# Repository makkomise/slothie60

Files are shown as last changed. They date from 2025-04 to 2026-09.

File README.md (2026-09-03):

# Slothie60

## 60% ISO keyboard

- GH60-Compatible
- Underglow
- Support for split Right Shift and stepped Caps
- Support for QMK/VIAL






ORDERING AT YOUR OWN RESPONSIBILITY! While i have confirmed that this works, order at your own discretion.

Version 2a is a work in progress, 1b is the finished one so if you want to get one, pick that.
KiCad folder includes all the project files, feel free to modify to your own liking. 
Production folder includes all the needed files for ordering these. Zip has all the gerbers, BOM and POS files are needed if you order it assembled.
Firmware-folder has all the files needed for you to either modify and compile yourself, or you can just download the binary and flash it in QMK Toolbox.

Keyboard made under CERN-OHL-W v2 license.

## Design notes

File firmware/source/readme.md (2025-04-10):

# slothie60

slothie60

*60% ISO keyboard, support for GH60-cases, RGB underglow.*

* Keyboard Maintainer: [makkomise](https://github.com/makkomise)
* Hardware Availability: [github/makkomise/slothie60](https://github.com/makkomise/slothie60)

Make example for this keyboard (after setting up your build environment):

    make slothie60:default

Flashing example for this keyboard:

    make slothie60:default:flash

See the [build environment setup](https://docs.qmk.fm/#/getting_started_build_tools) and the [make instructions](https://docs.qmk.fm/#/getting_started_make_guide) for more information. Brand new to QMK? Start with our [Complete Newbs Guide](https://docs.qmk.fm/#/newbs).

## Bootloader

Enter the bootloader in 3 ways:

* **Bootmagic reset**: Hold down the key at (0,0) in the matrix (usually the top left key or Escape) and plug in the keyboard
* **Physical reset button**: Briefly press the button on the back of the PCB
* **Keycode in layout**: Press FN + Esc

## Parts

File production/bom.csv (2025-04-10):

Designator | Footprint | Quantity | Value | LCSC Part #
BOOTSW1 | SW_SPST_TL3342 | 1 | SW_Push | C115351
BOOT_R1 | 0603 | 1 | 10k | C25804
D1, D10, D11, D12, D13, D14, D15, D16, D17, D18, D19, D2, D20, D21, D22, D23, D24, D25, D26, D27, D28, D29, D3, D30, D32, D33, D4, D5, D6, D7, D8, D9 | SOT-23 | 32 | BAV70 | C2501
ESD1 | SOT-23-6 | 1 | USBLC6-2SC6 | C2827654
F1 | 1206 | 1 | 500mA | C135338
LED1, LED10, LED11, LED12, LED13, LED14, LED15, LED16, LED2, LED3, LED4, LED5, LED6, LED7, LED8, LED9 | LED_WS2812B_PLCC4_5.0x5.0mm_P3.2mm | 16 | Worldsemi_WS2812C | C114587
MCU1 | LQFP-48_7x7mm_P0.5mm | 1 | STM32F072CBT6 | C915660
MCU_C1, MCU_C2, MCU_C3, MCU_C5, MCU_C8 | 0603 | 5 | 100nF | C1591
MCU_C4, MCU_C9 | 0603 | 2 | 4.7uF | C19666
MCU_C6 | 0603 | 1 | 10nF | C57112
MCU_C7, REG_C1, REG_C2 | 0603 | 3 | 1uF | C15849
REG1 | SOT-23-3 | 1 | XC6206 | C5446
USB1 | USB_C_Receptacle_HRO_TYPE-C-31-M-12 | 1 | USB_C | C165948
USB_R1, USB_R2 | 0603 | 2 | 5.1k | C23186

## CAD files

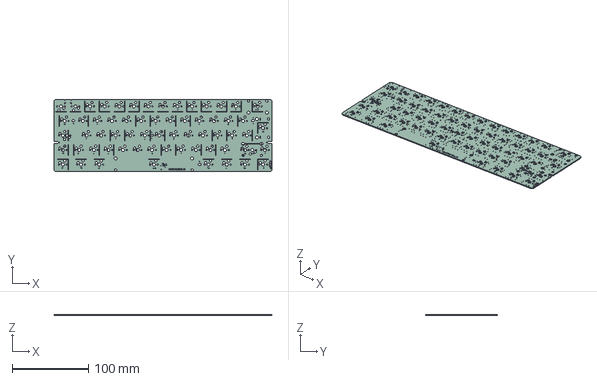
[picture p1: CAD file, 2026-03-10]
KiCad Files/rev1b/Slothie60_rev1b-rounded.step
285.0 x 94.6 x 1.26 mm
Slothie60_rev1b-rounded_silkscreen x 2
Slothie60_rev1b-rounded_PCB

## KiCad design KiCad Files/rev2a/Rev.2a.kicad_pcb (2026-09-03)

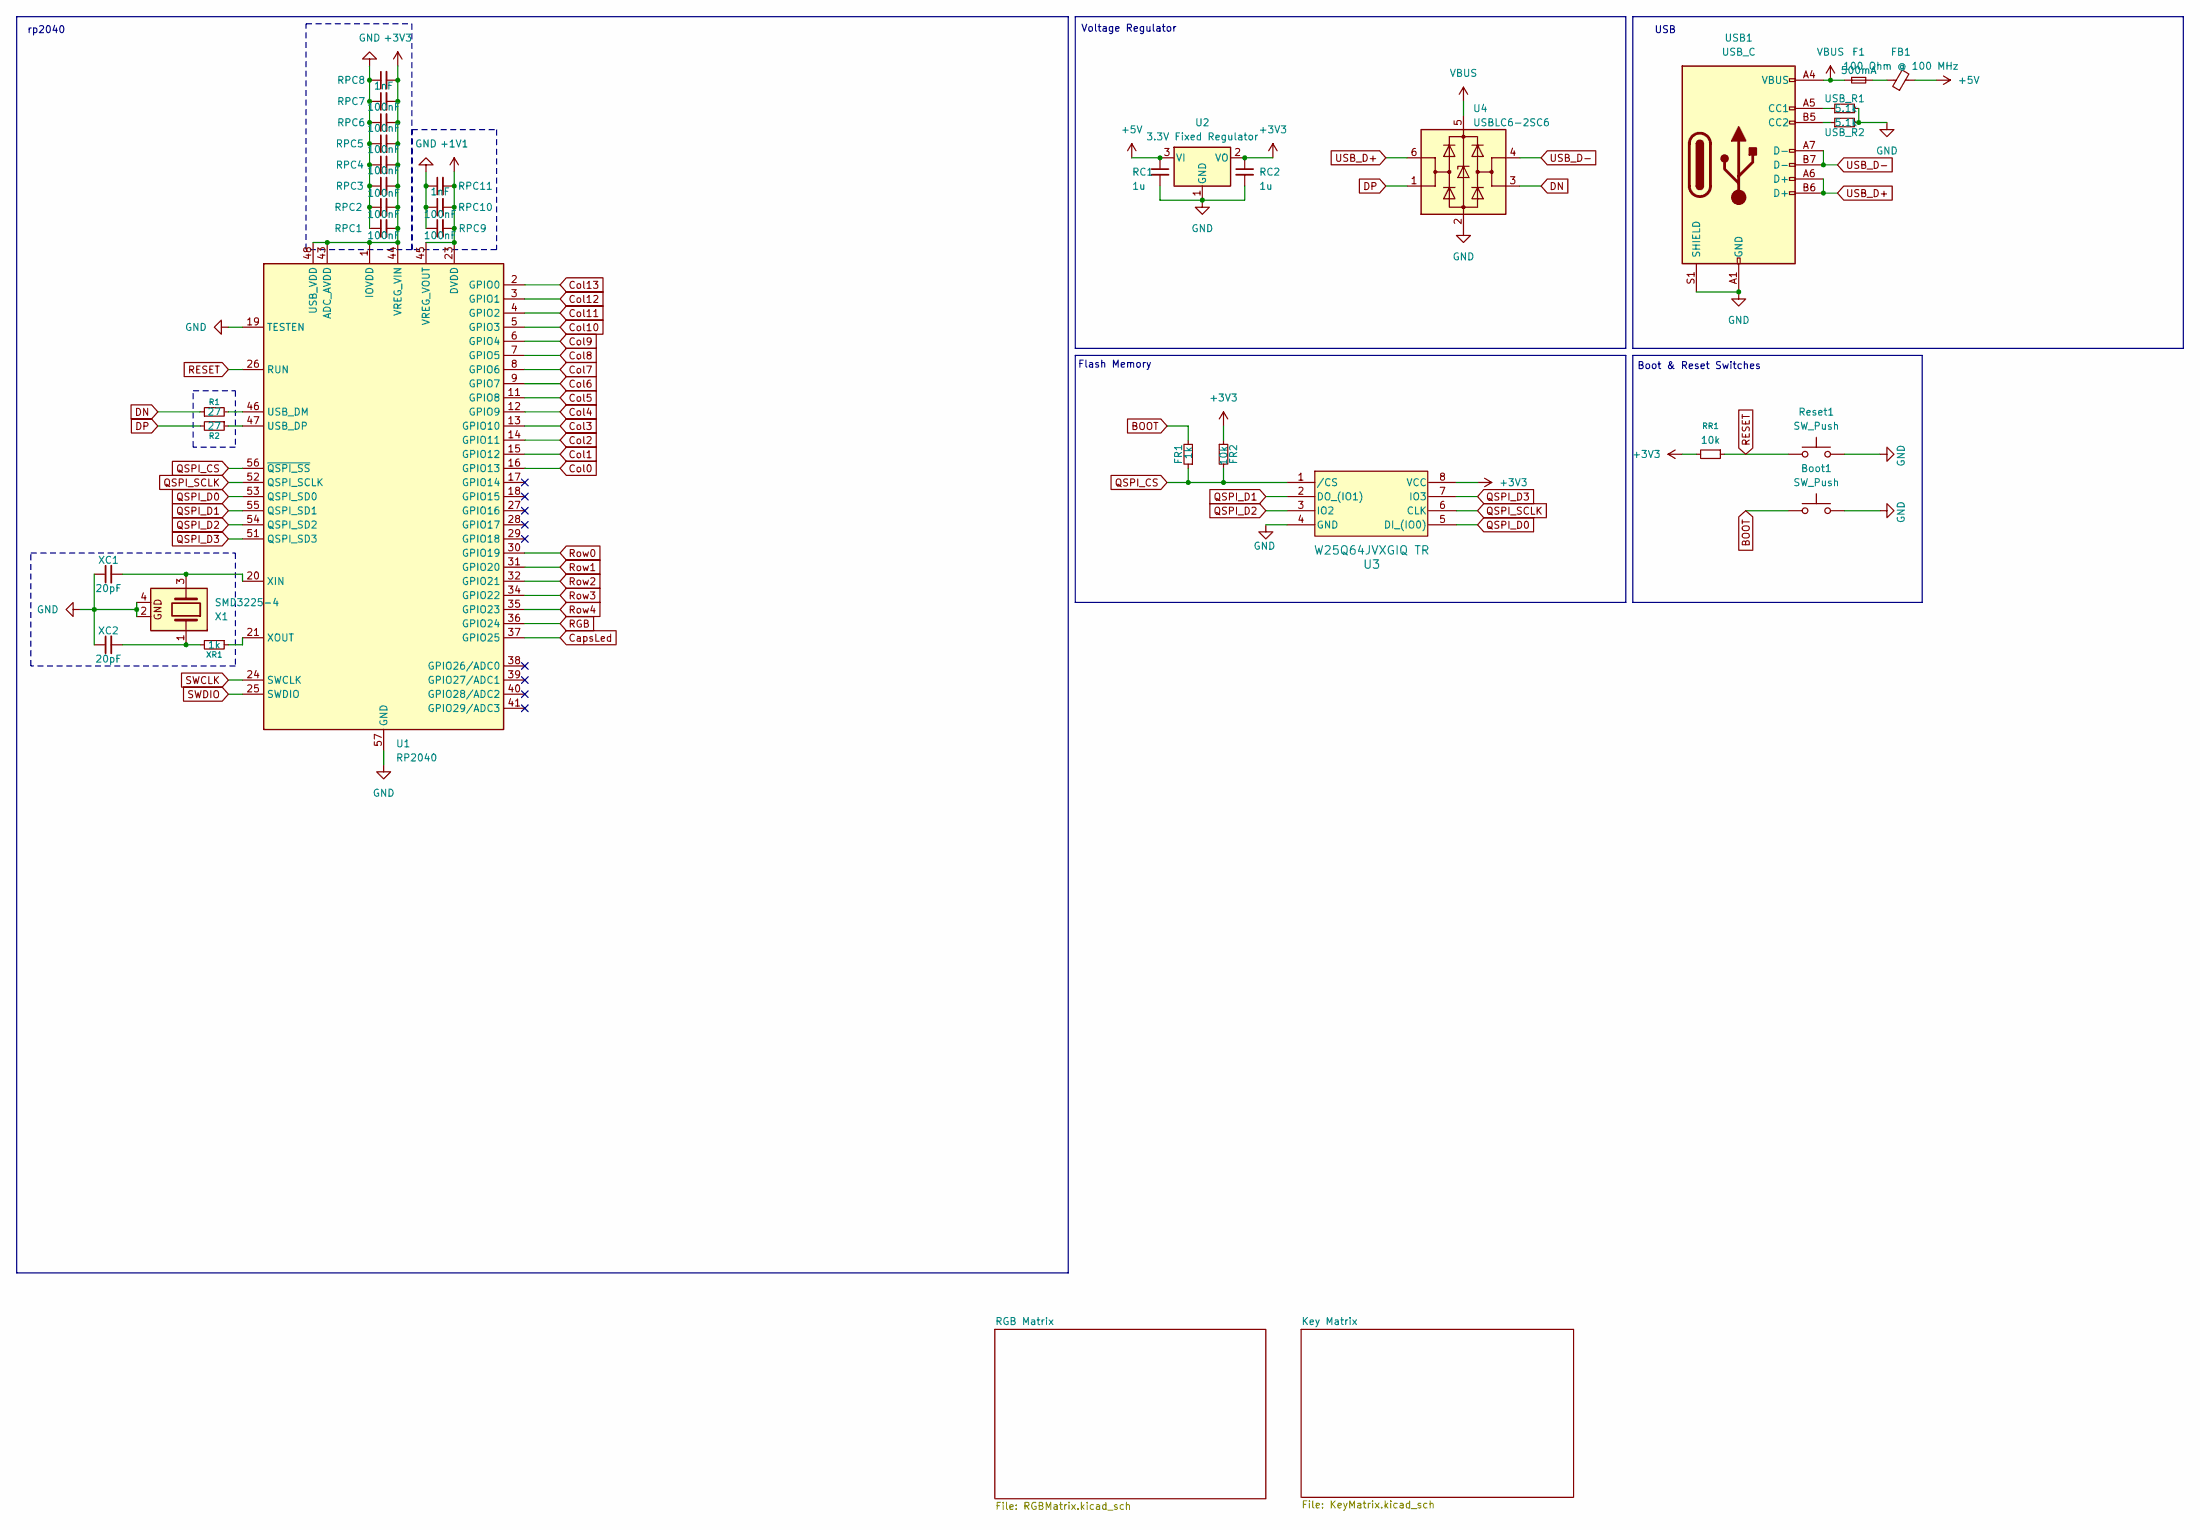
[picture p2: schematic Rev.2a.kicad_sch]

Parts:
Boot1: SW_Push; SW_SPST_B3U-1000P; LCSC C231329
F1: 500mA; Fuse_1206_3216Metric_Castellated; LCSC C135338
FB1: 100 Ohm @ 100 MHz; L_0402_1005Metric; LCSC C85812
FR1: 1k; R_0402_1005Metric; LCSC C23186
FR2: 10k; R_0402_1005Metric; LCSC C23186
R1, R2: 27; R_0402_1005Metric; LCSC C25100
RC1, RC2: 1u; C_0402_1005Metric; LCSC C52923
RPC1, RPC2, RPC3, RPC4, RPC5, RPC6, RPC7, RPC9, RPC10: 100nF; C_0402_1005Metric; LCSC C307331
RPC8, RPC11: 1nF; C_0402_1005Metric; LCSC C14442
RR1: 10k; R_0402_1005Metric; LCSC C23186
Reset1: SW_Push; SW_SPST_B3U-1000P; LCSC C231329
U1: RP2040; QFN-56-1EP_7x7mm_P0.4mm_EP3.2x3.2mm; LCSC C2040
U2: 3.3V Fixed Regulator; TSOT-23; LCSC C150715
U3: W25Q64JVXGIQ TR; XSON-8-EP(4x4); LCSC C2940195
U4: USBLC6-2SC6; SOT-23-6; LCSC C558442
USB1: USB_C; USB_C_Receptacle_HRO_TYPE-C-31-M-12; LCSC C165948
USB_R1, USB_R2: 5.1k; R_0402_1005Metric; LCSC C23186
X1: SMD3225-4; Crystal_SMD_3225-4Pin_3.2x2.5mm; LCSC C9002
XC1, XC2: 20pF; C_0402_1005Metric; LCSC C1554
XR1: 1k; R_0402_1005Metric; LCSC C23186

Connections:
+1V1: RPC9.2, RPC10.2, RPC11.2, U1.23 (DVDD), U1.45 (VREG_VOUT), U1.50 (DVDD)
+3V3: FR2.1, RC2.1, RPC1.2, RPC2.2, RPC3.2, RPC4.2, RPC5.2, RPC6.2, RPC7.2, RPC8.2, RR1.2, U1.1 (IOVDD), U1.10 (IOVDD), U1.22 (IOVDD), U1.33 (IOVDD), U1.42 (IOVDD), U1.43 (ADC_AVDD), U1.44 (VREG_VIN), U1.48 (USB_VDD), U1.49 (IOVDD), U2.2 (VO), U3.8 (VCC)
+5V: FB1.2, RC1.1, U2.3 (VI); also elsewhere on the board
BOOT: Boot1.1, FR1.2
CapsLed: U1.37 (GPIO25); also elsewhere on the board
Col0: U1.16 (GPIO13); also elsewhere on the board
Col1: U1.15 (GPIO12); also elsewhere on the board
Col2: U1.14 (GPIO11); also elsewhere on the board
Col3: U1.13 (GPIO10); also elsewhere on the board
Col4: U1.12 (GPIO9); also elsewhere on the board
Col5: U1.11 (GPIO8); also elsewhere on the board
Col6: U1.9 (GPIO7); also elsewhere on the board
Col7: U1.8 (GPIO6); also elsewhere on the board
Col8: U1.7 (GPIO5); also elsewhere on the board
Col9: U1.6 (GPIO4); also elsewhere on the board
Col10: U1.5 (GPIO3); also elsewhere on the board
Col11: U1.4 (GPIO2); also elsewhere on the board
Col12: U1.3 (GPIO1); also elsewhere on the board
Col13: U1.2 (GPIO0); also elsewhere on the board
DN: R1.1, U4.3 (I/O2)
DP: R2.2, U4.1 (I/O1)
GND: Boot1.2, RC1.2, RC2.2, RPC1.1, RPC2.1, RPC3.1, RPC4.1, RPC5.1, RPC6.1, RPC7.1, RPC8.1, RPC9.1, RPC10.1, RPC11.1, Reset1.2, U1.19 (TESTEN), U1.57 (GND), U2.1 (GND), U3.4 (GND), U4.2 (GND), USB1.A1 (GND), USB1.A12 (GND), USB1.B1 (GND), USB1.B12 (GND), USB1.S1 (SHIELD), USB_R1.2, USB_R2.2, X1.2, X1.4, XC1.1, XC2.1; also elsewhere on the board
unnamed: F1.2, FB1.1
unnamed: R1.2, U1.46 (USB_DM)
unnamed: R2.1, U1.47 (USB_DP)
unnamed: U1.20 (XIN), X1.3, XC1.2
unnamed: U1.21 (XOUT), XR1.1
unnamed: USB1.A5 (CC1), USB_R1.1
unnamed: USB1.B5 (CC2), USB_R2.1
unnamed: X1.1, XC2.2, XR1.2
QSPI_CS: FR1.1, FR2.2, U1.56 (~QSPI_SS), U3.1 (/CS)
QSPI_D0: U1.53 (QSPI_SD0), U3.5 (DI_(IO0))
QSPI_D1: U1.55 (QSPI_SD1), U3.2 (DO_(IO1))
QSPI_D2: U1.54 (QSPI_SD2), U3.3 (IO2)
QSPI_D3: U1.51 (QSPI_SD3), U3.7 (IO3)
QSPI_SCLK: U1.52 (QSPI_SCLK), U3.6 (CLK)
RESET: RR1.1, Reset1.1, U1.26 (RUN)
RGB: U1.36 (GPIO24); also elsewhere on the board
Row0: U1.30 (GPIO19); also elsewhere on the board
Row1: U1.31 (GPIO20); also elsewhere on the board
Row2: U1.32 (GPIO21); also elsewhere on the board
Row3: U1.34 (GPIO22); also elsewhere on the board
Row4: U1.35 (GPIO23); also elsewhere on the board
SWCLK: U1.24 (SWCLK)
SWDIO: U1.25 (SWDIO)
USB_D+: U4.6 (I/O1), USB1.A6 (D+), USB1.B6 (D+)
USB_D-: U4.4 (I/O2), USB1.A7 (D-), USB1.B7 (D-)
VBUS: F1.1, U4.5 (VBUS), USB1.A4 (VBUS), USB1.A9 (VBUS), USB1.B4 (VBUS), USB1.B9 (VBUS)

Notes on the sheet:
USB
Voltage Regulator
Boot & Reset Switches
Flash Memory
rp2040

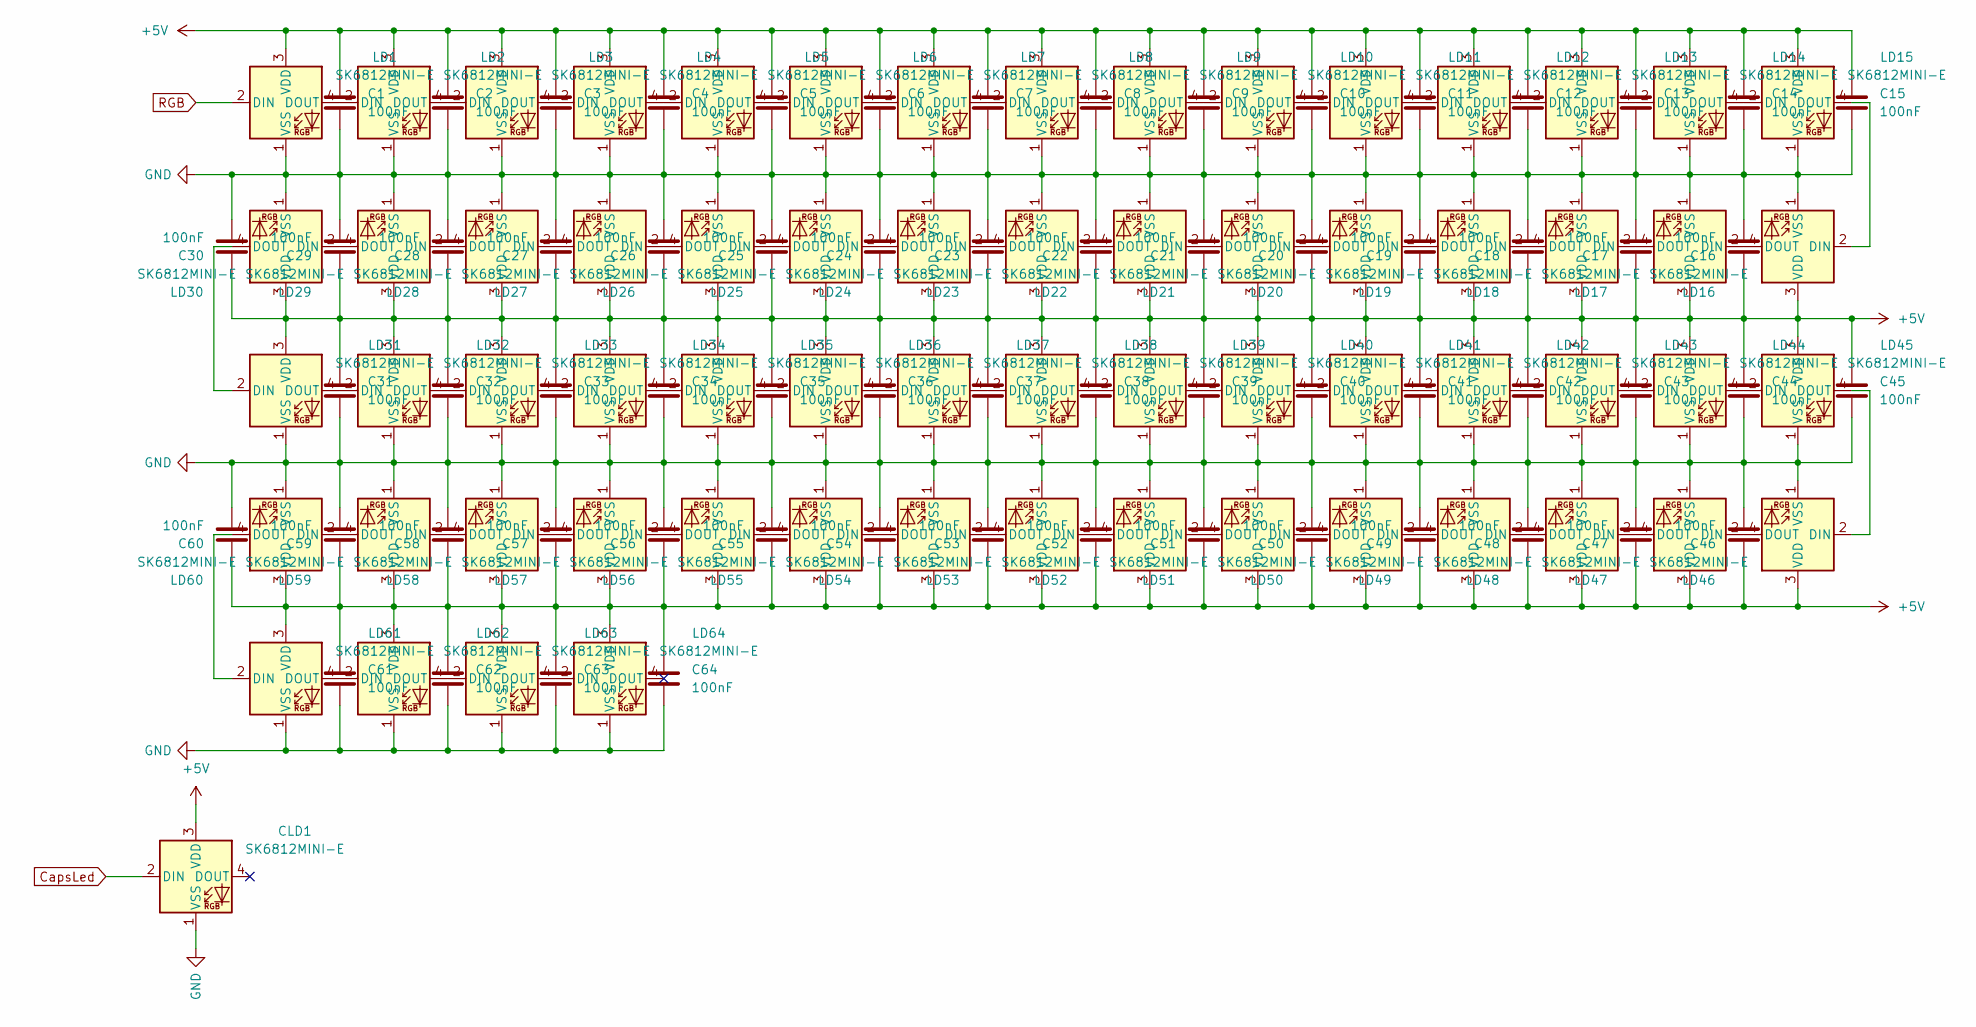
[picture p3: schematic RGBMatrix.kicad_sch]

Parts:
C1, C2, C3, C4, C5, C6, C7, C8, C9, C10, C11, C12, C13, C14, C15, C16, C17, C18, C19, C20, C21, C22, C23, C24, C25, C26, C27, C28, C29, C30, C31, C32, C33, C34, C35, C36, C37, C38, C39, C40, C41, C42, C43, C44, C45, C46, C47, C48, C49, C50, C51, C52, C53, C54, C55, C56, C57, C58, C59, C60, C61, C62, C63, C64: 100nF; C_0402_1005Metric; LCSC C307331
CLD1: SK6812MINI-E; LED_SK6812MINI-E_3.2x2.8mm_P1.5mm_ReverseMount; LCSC C5149201
LD1, LD2, LD3, LD4, LD5, LD6, LD7, LD8, LD9, LD10, LD11, LD12, LD13, LD14, LD15, LD16, LD17, LD18, LD19, LD20, LD21, LD22, LD23, LD24, LD25, LD26, LD27, LD28, LD29, LD30, LD31, LD32, LD33, LD34, LD35, LD36, LD37, LD38, LD39, LD40, LD41, LD42, LD43, LD44, LD45, LD46, LD47, LD48, LD49, LD50, LD51, LD52, LD53, LD54, LD55, LD56, LD57, LD58, LD59, LD60, LD61, LD62, LD63, LD64: SK6812MINI-E; LED_SK6812MINI-E_3.2x2.8mm_P1.5mm_ReverseMount; LCSC C5149201

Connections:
+5V: C1.1, C2.1, C3.1, C4.1, C5.1, C6.1, C7.1, C8.1, C9.1, C10.1, C11.1, C12.1, C13.1, C14.1, C15.1, C16.1, C17.1, C18.1, C19.1, C20.1, C21.1, C22.1, C23.1, C24.1, C25.1, C26.1, C27.1, C28.1, C29.1, C30.1, C31.1, C32.1, C33.1, C34.1, C35.1, C36.1, C37.1, C38.1, C39.1, C40.1, C41.1, C42.1, C43.1, C44.1, C45.1, C46.1, C47.1, C48.1, C49.1, C50.1, C51.1, C52.1, C53.1, C54.1, C55.1, C56.1, C57.1, C58.1, C59.1, C60.1, C61.1, C62.1, C63.1, C64.1, CLD1.3 (VDD), LD1.3 (VDD), LD2.3 (VDD), LD3.3 (VDD), LD4.3 (VDD), LD5.3 (VDD), LD6.3 (VDD), LD7.3 (VDD), LD8.3 (VDD), LD9.3 (VDD), LD10.3 (VDD), LD11.3 (VDD), LD12.3 (VDD), LD13.3 (VDD), LD14.3 (VDD), LD15.3 (VDD), LD16.3 (VDD), LD17.3 (VDD), LD18.3 (VDD), LD19.3 (VDD), LD20.3 (VDD), LD21.3 (VDD), LD22.3 (VDD), LD23.3 (VDD), LD24.3 (VDD), LD25.3 (VDD), LD26.3 (VDD), LD27.3 (VDD), LD28.3 (VDD), LD29.3 (VDD), LD30.3 (VDD), LD31.3 (VDD), LD32.3 (VDD), LD33.3 (VDD), LD34.3 (VDD), LD35.3 (VDD), LD36.3 (VDD), LD37.3 (VDD), LD38.3 (VDD), LD39.3 (VDD), LD40.3 (VDD), LD41.3 (VDD), LD42.3 (VDD), LD43.3 (VDD), LD44.3 (VDD), LD45.3 (VDD), LD46.3 (VDD), LD47.3 (VDD), LD48.3 (VDD), LD49.3 (VDD), LD50.3 (VDD), LD51.3 (VDD), LD52.3 (VDD), LD53.3 (VDD), LD54.3 (VDD), LD55.3 (VDD), LD56.3 (VDD), LD57.3 (VDD), LD58.3 (VDD), LD59.3 (VDD), LD60.3 (VDD), LD61.3 (VDD), LD62.3 (VDD), LD63.3 (VDD), LD64.3 (VDD); also elsewhere on the board
CapsLed: CLD1.2 (DIN); also elsewhere on the board
GND: C1.2, C2.2, C3.2, C4.2, C5.2, C6.2, C7.2, C8.2, C9.2, C10.2, C11.2, C12.2, C13.2, C14.2, C15.2, C16.2, C17.2, C18.2, C19.2, C20.2, C21.2, C22.2, C23.2, C24.2, C25.2, C26.2, C27.2, C28.2, C29.2, C30.2, C31.2, C32.2, C33.2, C34.2, C35.2, C36.2, C37.2, C38.2, C39.2, C40.2, C41.2, C42.2, C43.2, C44.2, C45.2, C46.2, C47.2, C48.2, C49.2, C50.2, C51.2, C52.2, C53.2, C54.2, C55.2, C56.2, C57.2, C58.2, C59.2, C60.2, C61.2, C62.2, C63.2, C64.2, CLD1.1 (VSS), LD1.1 (VSS), LD2.1 (VSS), LD3.1 (VSS), LD4.1 (VSS), LD5.1 (VSS), LD6.1 (VSS), LD7.1 (VSS), LD8.1 (VSS), LD9.1 (VSS), LD10.1 (VSS), LD11.1 (VSS), LD12.1 (VSS), LD13.1 (VSS), LD14.1 (VSS), LD15.1 (VSS), LD16.1 (VSS), LD17.1 (VSS), LD18.1 (VSS), LD19.1 (VSS), LD20.1 (VSS), LD21.1 (VSS), LD22.1 (VSS), LD23.1 (VSS), LD24.1 (VSS), LD25.1 (VSS), LD26.1 (VSS), LD27.1 (VSS), LD28.1 (VSS), LD29.1 (VSS), LD30.1 (VSS), LD31.1 (VSS), LD32.1 (VSS), LD33.1 (VSS), LD34.1 (VSS), LD35.1 (VSS), LD36.1 (VSS), LD37.1 (VSS), LD38.1 (VSS), LD39.1 (VSS), LD40.1 (VSS), LD41.1 (VSS), LD42.1 (VSS), LD43.1 (VSS), LD44.1 (VSS), LD45.1 (VSS), LD46.1 (VSS), LD47.1 (VSS), LD48.1 (VSS), LD49.1 (VSS), LD50.1 (VSS), LD51.1 (VSS), LD52.1 (VSS), LD53.1 (VSS), LD54.1 (VSS), LD55.1 (VSS), LD56.1 (VSS), LD57.1 (VSS), LD58.1 (VSS), LD59.1 (VSS), LD60.1 (VSS), LD61.1 (VSS), LD62.1 (VSS), LD63.1 (VSS), LD64.1 (VSS); also elsewhere on the board
unnamed: LD1.4 (DOUT), LD2.2 (DIN)
unnamed: LD2.4 (DOUT), LD3.2 (DIN)
unnamed: LD3.4 (DOUT), LD4.2 (DIN)
unnamed: LD4.4 (DOUT), LD5.2 (DIN)
unnamed: LD5.4 (DOUT), LD6.2 (DIN)
unnamed: LD6.4 (DOUT), LD7.2 (DIN)
unnamed: LD7.4 (DOUT), LD8.2 (DIN)
unnamed: LD8.4 (DOUT), LD9.2 (DIN)
unnamed: LD9.4 (DOUT), LD10.2 (DIN)
unnamed: LD10.4 (DOUT), LD11.2 (DIN)
unnamed: LD11.4 (DOUT), LD12.2 (DIN)
unnamed: LD12.4 (DOUT), LD13.2 (DIN)
unnamed: LD13.4 (DOUT), LD14.2 (DIN)
unnamed: LD14.4 (DOUT), LD15.2 (DIN)
unnamed: LD15.4 (DOUT), LD16.2 (DIN)
unnamed: LD16.4 (DOUT), LD17.2 (DIN)
unnamed: LD17.4 (DOUT), LD18.2 (DIN)
unnamed: LD18.4 (DOUT), LD19.2 (DIN)
unnamed: LD19.4 (DOUT), LD20.2 (DIN)
unnamed: LD20.4 (DOUT), LD21.2 (DIN)
unnamed: LD21.4 (DOUT), LD22.2 (DIN)
unnamed: LD22.4 (DOUT), LD23.2 (DIN)
unnamed: LD23.4 (DOUT), LD24.2 (DIN)
unnamed: LD24.4 (DOUT), LD25.2 (DIN)
unnamed: LD25.4 (DOUT), LD26.2 (DIN)
unnamed: LD26.4 (DOUT), LD27.2 (DIN)
unnamed: LD27.4 (DOUT), LD28.2 (DIN)
unnamed: LD28.4 (DOUT), LD29.2 (DIN)
unnamed: LD29.4 (DOUT), LD30.2 (DIN)
unnamed: LD30.4 (DOUT), LD31.2 (DIN)
unnamed: LD31.4 (DOUT), LD32.2 (DIN)
unnamed: LD32.4 (DOUT), LD33.2 (DIN)
unnamed: LD33.4 (DOUT), LD34.2 (DIN)
unnamed: LD34.4 (DOUT), LD35.2 (DIN)
unnamed: LD35.4 (DOUT), LD36.2 (DIN)
unnamed: LD36.4 (DOUT), LD37.2 (DIN)
unnamed: LD37.4 (DOUT), LD38.2 (DIN)
unnamed: LD38.4 (DOUT), LD39.2 (DIN)
unnamed: LD39.4 (DOUT), LD40.2 (DIN)
unnamed: LD40.4 (DOUT), LD41.2 (DIN)
unnamed: LD41.4 (DOUT), LD42.2 (DIN)
unnamed: LD42.4 (DOUT), LD43.2 (DIN)
unnamed: LD43.4 (DOUT), LD44.2 (DIN)
unnamed: LD44.4 (DOUT), LD45.2 (DIN)
unnamed: LD45.4 (DOUT), LD46.2 (DIN)
unnamed: LD46.4 (DOUT), LD47.2 (DIN)
unnamed: LD47.4 (DOUT), LD48.2 (DIN)
unnamed: LD48.4 (DOUT), LD49.2 (DIN)
unnamed: LD49.4 (DOUT), LD50.2 (DIN)
unnamed: LD50.4 (DOUT), LD51.2 (DIN)
unnamed: LD51.4 (DOUT), LD52.2 (DIN)
unnamed: LD52.4 (DOUT), LD53.2 (DIN)
unnamed: LD53.4 (DOUT), LD54.2 (DIN)
unnamed: LD54.4 (DOUT), LD55.2 (DIN)
unnamed: LD55.4 (DOUT), LD56.2 (DIN)
unnamed: LD56.4 (DOUT), LD57.2 (DIN)
unnamed: LD57.4 (DOUT), LD58.2 (DIN)
unnamed: LD58.4 (DOUT), LD59.2 (DIN)
unnamed: LD59.4 (DOUT), LD60.2 (DIN)
unnamed: LD60.4 (DOUT), LD61.2 (DIN)
unnamed: LD61.4 (DOUT), LD62.2 (DIN)
unnamed: LD62.4 (DOUT), LD63.2 (DIN)
unnamed: LD63.4 (DOUT), LD64.2 (DIN)
RGB: LD1.2 (DIN); also elsewhere on the board

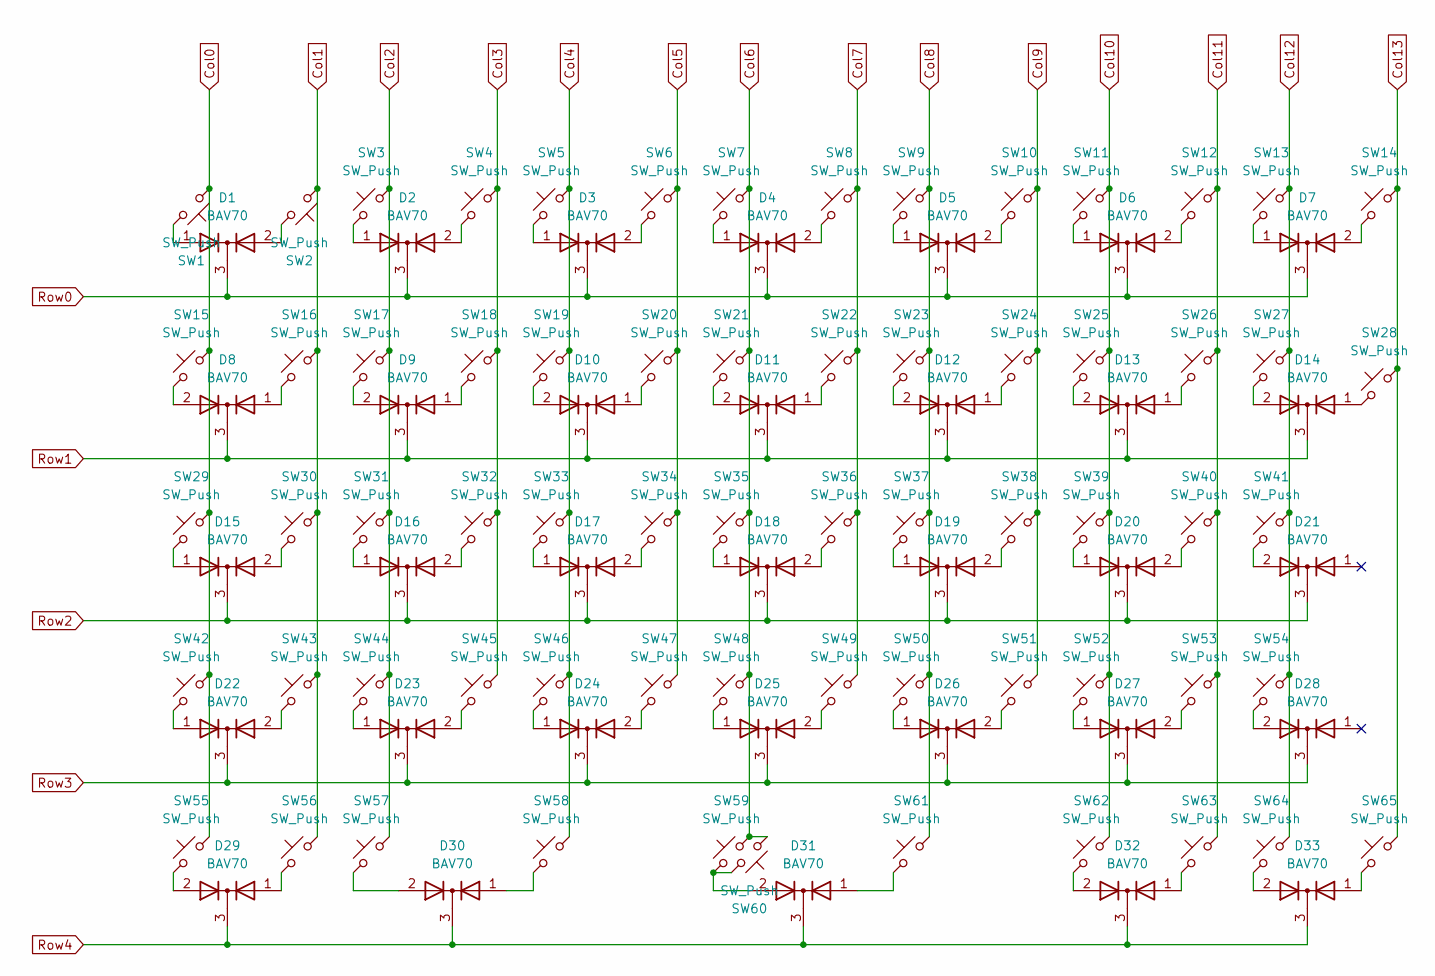
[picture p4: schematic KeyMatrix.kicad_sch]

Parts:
D1, D2, D3, D4, D5, D6, D7, D8, D9, D10, D11, D12, D13, D14, D15, D16, D17, D18, D19, D20, D21, D22, D23, D24, D25, D26, D27, D28, D29, D30, D31, D32, D33: BAV70; SOT-23; LCSC C2501
SW1, SW2, SW3, SW4, SW5, SW6, SW7, SW8, SW9, SW10, SW11, SW12, SW13, SW16, SW17, SW18, SW19, SW20, SW21, SW22, SW23, SW24, SW25, SW26, SW27, SW30, SW31, SW32, SW33, SW34, SW35, SW36, SW37, SW38, SW39, SW40, SW41, SW43, SW44, SW45, SW46, SW47, SW48, SW49, SW50, SW51, SW52, SW53: SW_Push; SW_Hotswap_Kailh_MX_Plated_1.00u; LCSC C5156480
SW14: SW_Push; SW_Hotswap_Kailh_MX_Plated_2.00u; LCSC C5156480
SW15: SW_Push; SW_Hotswap_Kailh_MX_Plated_1.50u; LCSC C5156480
SW28: SW_Push; SW_Hotswap_Kailh_MX_Plated_ISOEnter; LCSC C5156480
SW29: SW_Push; SW_Hotswap_Kailh_MX_Plated_1.75u; LCSC C5156480
SW42, SW55, SW56, SW57, SW60, SW62, SW63, SW64, SW65: SW_Push; SW_Hotswap_Kailh_MX_Plated_1.25u; LCSC C5156480
SW54, SW58: SW_Push; SW_Hotswap_Kailh_MX_Plated_2.75u; LCSC C5156480
SW59: SW_Push; SW_Hotswap_Kailh_MX_Plated_6.25u; LCSC C5156480
SW61: SW_Push; SW_Hotswap_Kailh_MX_Plated_2.25u; LCSC C5156480

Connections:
Col0: SW1.2, SW15.1, SW29.1, SW42.1, SW55.1; also elsewhere on the board
Col1: SW2.2, SW16.1, SW30.1, SW43.1, SW56.1; also elsewhere on the board
Col2: SW3.1, SW17.1, SW31.1, SW44.1, SW57.1; also elsewhere on the board
Col3: SW4.1, SW18.1, SW32.1, SW45.1; also elsewhere on the board
Col4: SW5.1, SW19.1, SW33.1, SW46.1, SW58.1; also elsewhere on the board
Col5: SW6.1, SW20.1, SW34.1, SW47.1; also elsewhere on the board
Col6: SW7.1, SW21.1, SW35.1, SW48.1, SW59.1, SW60.2; also elsewhere on the board
Col7: SW8.1, SW22.1, SW36.1, SW49.1; also elsewhere on the board
Col8: SW9.1, SW23.1, SW37.1, SW50.1, SW61.1; also elsewhere on the board
Col9: SW10.1, SW24.1, SW38.1, SW51.1; also elsewhere on the board
Col10: SW11.1, SW25.1, SW39.1, SW52.1, SW62.1; also elsewhere on the board
Col11: SW12.1, SW26.1, SW40.1, SW53.1, SW63.1; also elsewhere on the board
Col12: SW13.1, SW27.1, SW41.1, SW54.1, SW64.1; also elsewhere on the board
Col13: SW14.1, SW28.1, SW65.1; also elsewhere on the board
unnamed: D1.1 (A), SW1.1
unnamed: D1.2 (A), SW2.1
unnamed: D2.1 (A), SW3.2
unnamed: D2.2 (A), SW4.2
unnamed: D3.1 (A), SW5.2
unnamed: D3.2 (A), SW6.2
unnamed: D4.1 (A), SW7.2
unnamed: D4.2 (A), SW8.2
unnamed: D5.1 (A), SW9.2
unnamed: D5.2 (A), SW10.2
unnamed: D6.1 (A), SW11.2
unnamed: D6.2 (A), SW12.2
unnamed: D7.1 (A), SW13.2
unnamed: D7.2 (A), SW14.2
unnamed: D8.1 (A), SW16.2
unnamed: D8.2 (A), SW15.2
unnamed: D9.1 (A), SW18.2
unnamed: D9.2 (A), SW17.2
unnamed: D10.1 (A), SW20.2
unnamed: D10.2 (A), SW19.2
unnamed: D11.1 (A), SW22.2
unnamed: D11.2 (A), SW21.2
unnamed: D12.1 (A), SW24.2
unnamed: D12.2 (A), SW23.2
unnamed: D13.1 (A), SW26.2
unnamed: D13.2 (A), SW25.2
unnamed: D14.1 (A), SW28.2
unnamed: D14.2 (A), SW27.2
unnamed: D15.1 (A), SW29.2
unnamed: D15.2 (A), SW30.2
unnamed: D16.1 (A), SW31.2
unnamed: D16.2 (A), SW32.2
unnamed: D17.1 (A), SW33.2
unnamed: D17.2 (A), SW34.2
unnamed: D18.1 (A), SW35.2
unnamed: D18.2 (A), SW36.2
unnamed: D19.1 (A), SW37.2
unnamed: D19.2 (A), SW38.2
unnamed: D20.1 (A), SW39.2
unnamed: D20.2 (A), SW40.2
unnamed: D21.2 (A), SW41.2
unnamed: D22.1 (A), SW42.2
unnamed: D22.2 (A), SW43.2
unnamed: D23.1 (A), SW44.2
unnamed: D23.2 (A), SW45.2
unnamed: D24.1 (A), SW46.2
unnamed: D24.2 (A), SW47.2
unnamed: D25.1 (A), SW48.2
unnamed: D25.2 (A), SW49.2
unnamed: D26.1 (A), SW50.2
unnamed: D26.2 (A), SW51.2
unnamed: D27.1 (A), SW52.2
unnamed: D27.2 (A), SW53.2
unnamed: D28.2 (A), SW54.2
unnamed: D29.1 (A), SW56.2
unnamed: D29.2 (A), SW55.2
unnamed: D30.1 (A), SW58.2
unnamed: D30.2 (A), SW57.2
unnamed: D31.1 (A), SW61.2
unnamed: D31.2 (A), SW59.2, SW60.1
unnamed: D32.1 (A), SW63.2
unnamed: D32.2 (A), SW62.2
unnamed: D33.1 (A), SW65.2
unnamed: D33.2 (A), SW64.2
Row0: D1.3 (K), D2.3 (K), D3.3 (K), D4.3 (K), D5.3 (K), D6.3 (K), D7.3 (K); also elsewhere on the board
Row1: D8.3 (K), D9.3 (K), D10.3 (K), D11.3 (K), D12.3 (K), D13.3 (K), D14.3 (K); also elsewhere on the board
Row2: D15.3 (K), D16.3 (K), D17.3 (K), D18.3 (K), D19.3 (K), D20.3 (K), D21.3 (K); also elsewhere on the board
Row3: D22.3 (K), D23.3 (K), D24.3 (K), D25.3 (K), D26.3 (K), D27.3 (K), D28.3 (K); also elsewhere on the board
Row4: D29.3 (K), D30.3 (K), D31.3 (K), D32.3 (K), D33.3 (K); also elsewhere on the board

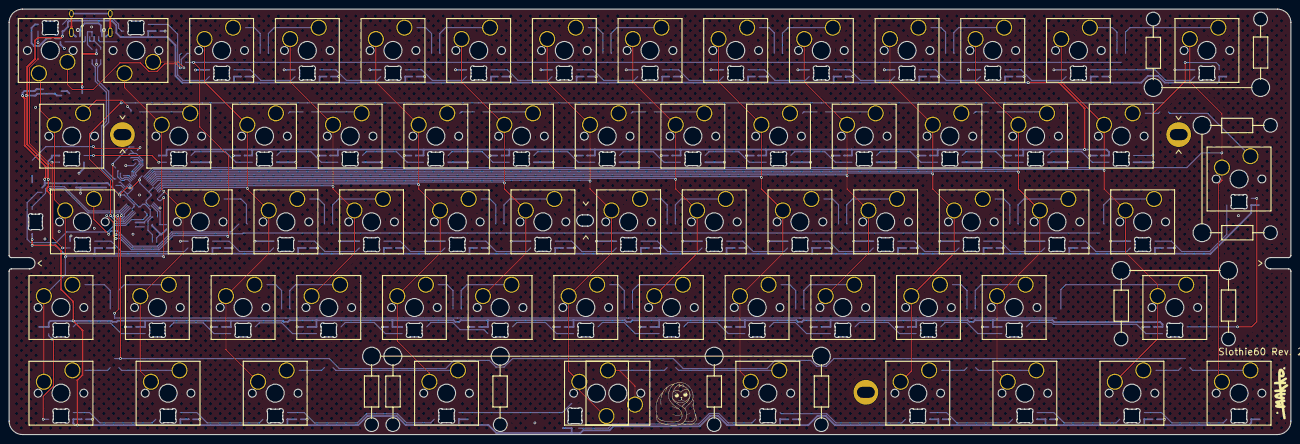
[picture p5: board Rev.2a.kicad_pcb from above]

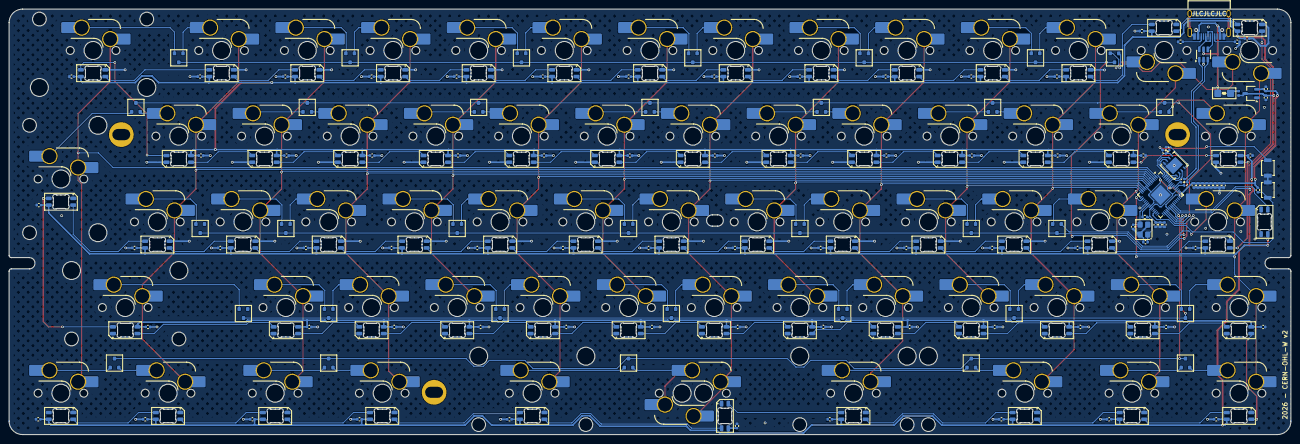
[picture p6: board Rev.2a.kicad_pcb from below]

Board: 2 copper layers, 285.0 x 94.6 mm, 260 parts (195 on the bottom side), 173 nets.

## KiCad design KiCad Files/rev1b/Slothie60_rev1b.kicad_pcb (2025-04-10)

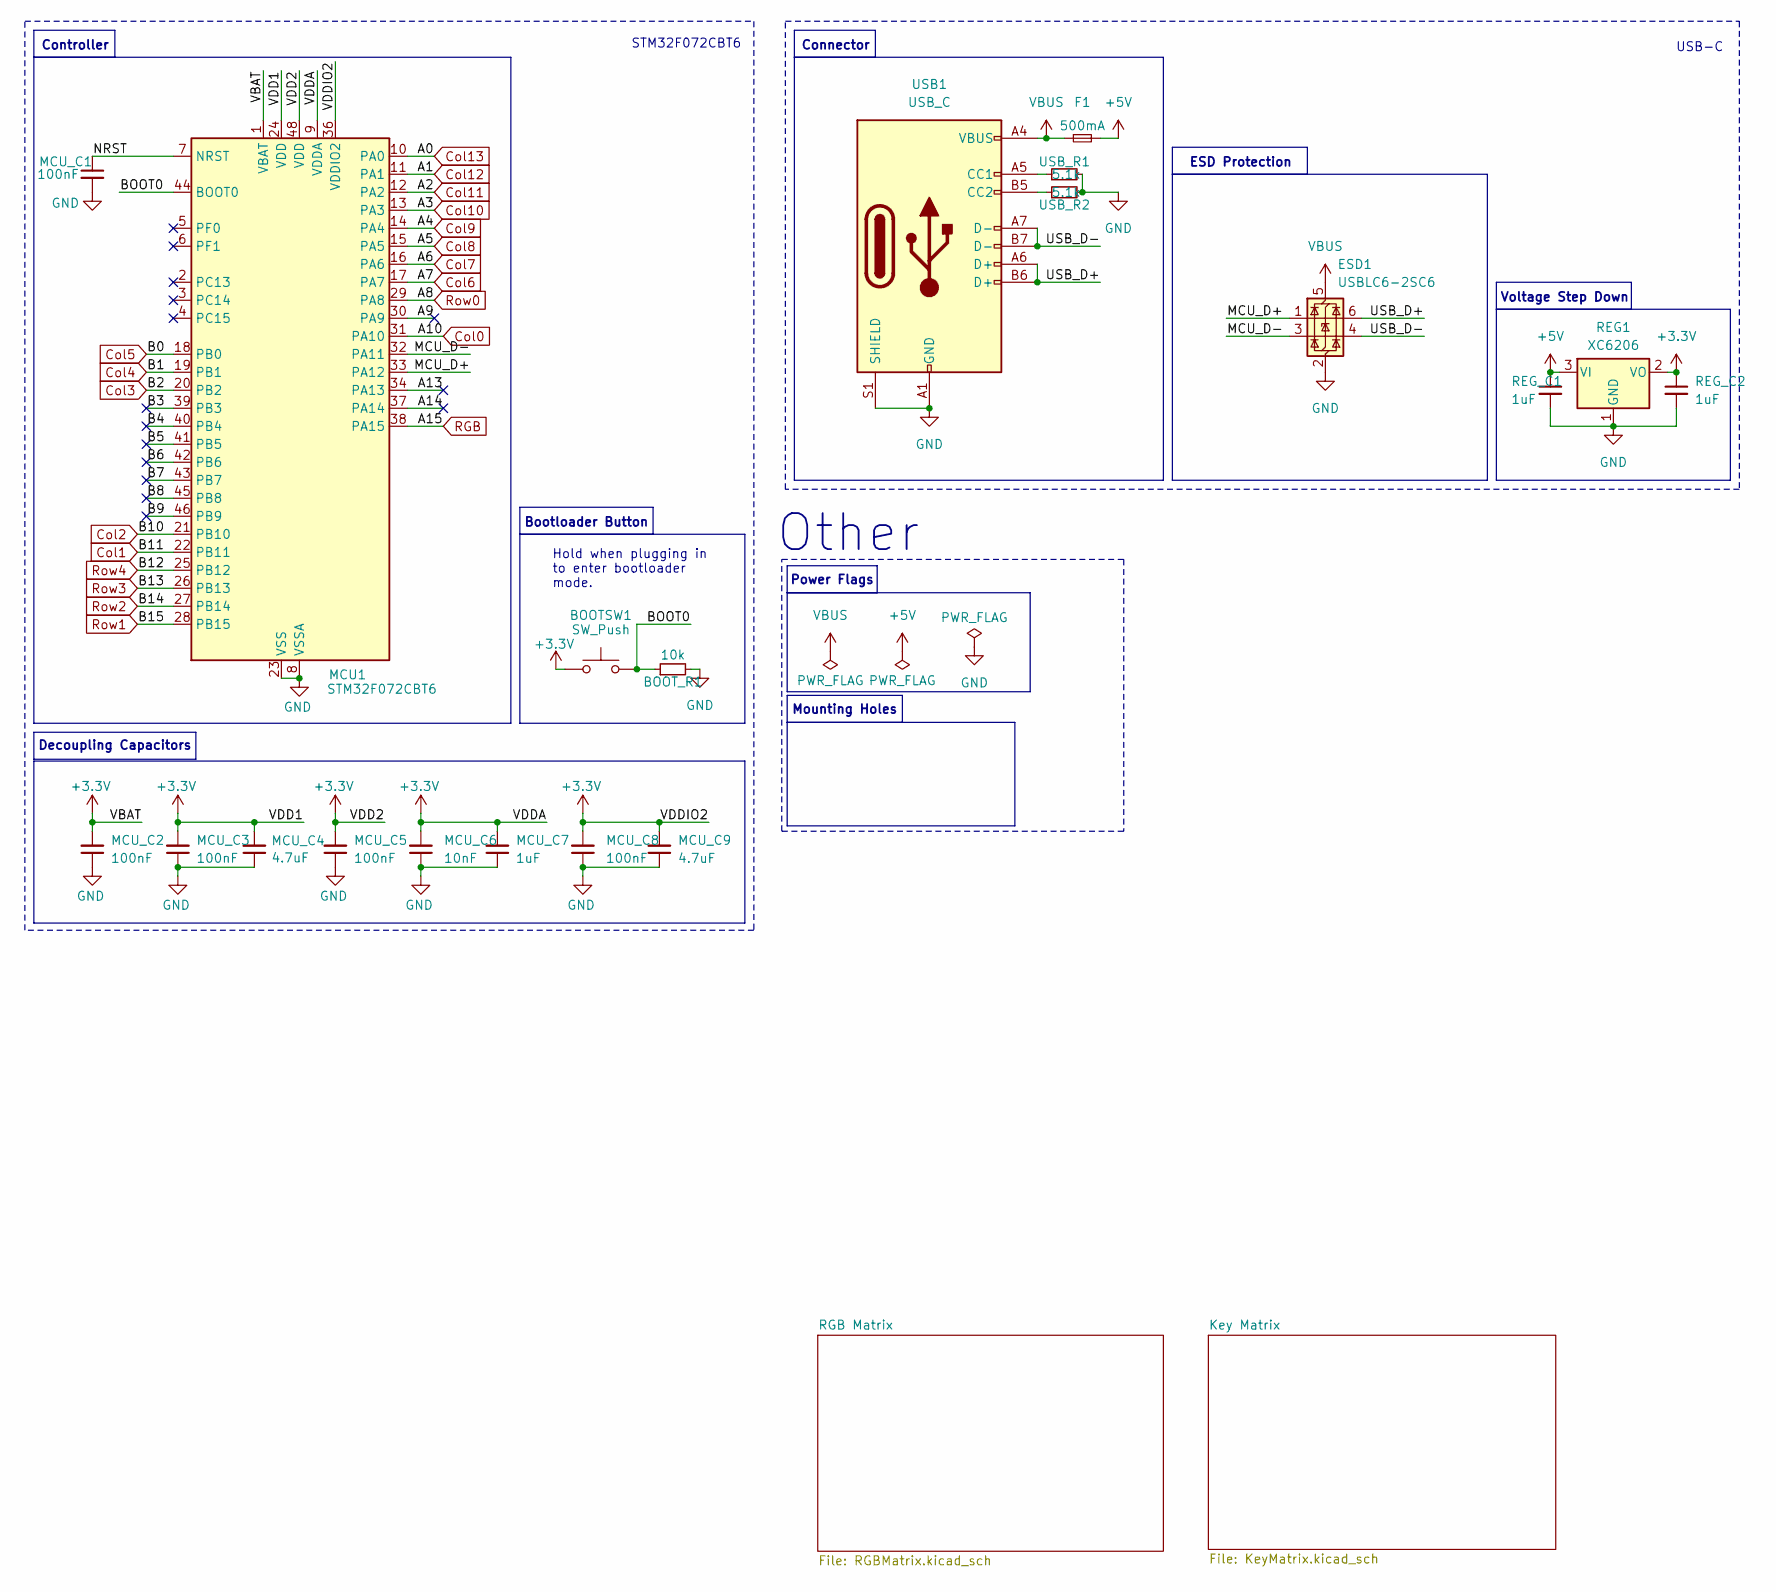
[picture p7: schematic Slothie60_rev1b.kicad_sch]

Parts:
BOOTSW1: SW_Push; SW_SPST_TL3342; LCSC C115351
BOOT_R1: 10k; R_0603_1608Metric; LCSC C25804
ESD1: USBLC6-2SC6; SOT-23-6; LCSC C2827654
F1: 500mA; Fuse_1206_3216Metric_Castellated; LCSC C135338
MCU1: STM32F072CBT6; LQFP-48_7x7mm_P0.5mm; LCSC C915660
MCU_C1: 100nF; C_0603_1608Metric; LCSC C1591
MCU_C2, MCU_C3, MCU_C5, MCU_C8: 100nF; C_0603_1608Metric; MPN CL05B104KB54PNC; LCSC C1591
MCU_C4, MCU_C9: 4.7uF; C_0603_1608Metric; MPN CL05A475MP5NRNC; LCSC C19666
MCU_C6: 10nF; C_0603_1608Metric; MPN CL05B103KB5NNNC; LCSC C57112
MCU_C7: 1uF; C_0603_1608Metric; MPN CL05A105KA5NQNC; LCSC C15849
REG1: XC6206; SOT-23-3; LCSC C5446
REG_C1, REG_C2: 1uF; C_0603_1608Metric; LCSC C15849
USB1: USB_C; USB_C_Receptacle_HRO_TYPE-C-31-M-12; LCSC C165948
USB_R1, USB_R2: 5.1k; R_0603_1608Metric; LCSC C23186

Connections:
+3.3V: BOOTSW1.1, MCU1.1 (VBAT), MCU1.9 (VDDA), MCU1.24 (VDD), MCU1.36 (VDDIO2), MCU1.48 (VDD), MCU_C2.2, MCU_C3.2, MCU_C4.2, MCU_C5.2, MCU_C6.2, MCU_C7.2, MCU_C8.2, MCU_C9.2, REG1.2 (VO), REG_C2.1
+5V: F1.2, REG1.3 (VI), REG_C1.1; also elsewhere on the board
/A9: MCU1.30 (PA9)
/A13: MCU1.34 (PA13)
/A14: MCU1.37 (PA14)
/B3: MCU1.39 (PB3)
/B4: MCU1.40 (PB4)
/B5: MCU1.41 (PB5)
/B6: MCU1.42 (PB6)
/B7: MCU1.43 (PB7)
/B8: MCU1.45 (PB8)
/B9: MCU1.46 (PB9)
/BOOT0: BOOTSW1.2, BOOT_R1.1, MCU1.44 (BOOT0)
/MCU_D+: ESD1.1 (I/O1), MCU1.33 (PA12)
/MCU_D-: ESD1.3 (I/O2), MCU1.32 (PA11)
/NRST: MCU1.7 (NRST), MCU_C1.1
/USB_D+: ESD1.6 (I/O1), USB1.A6 (D+), USB1.B6 (D+)
/USB_D-: ESD1.4 (I/O2), USB1.A7 (D-), USB1.B7 (D-)
Col0: MCU1.31 (PA10); also elsewhere on the board
Col1: MCU1.22 (PB11); also elsewhere on the board
Col2: MCU1.21 (PB10); also elsewhere on the board
Col3: MCU1.20 (PB2); also elsewhere on the board
Col4: MCU1.19 (PB1); also elsewhere on the board
Col5: MCU1.18 (PB0); also elsewhere on the board
Col6: MCU1.17 (PA7); also elsewhere on the board
Col7: MCU1.16 (PA6); also elsewhere on the board
Col8: MCU1.15 (PA5); also elsewhere on the board
Col9: MCU1.14 (PA4); also elsewhere on the board
Col10: MCU1.13 (PA3); also elsewhere on the board
Col11: MCU1.12 (PA2); also elsewhere on the board
Col12: MCU1.11 (PA1); also elsewhere on the board
Col13: MCU1.10 (PA0); also elsewhere on the board
GND: BOOT_R1.2, ESD1.2 (GND), MCU1.8 (VSSA), MCU1.23 (VSS), MCU1.35 (VSS), MCU1.47 (VSS), MCU_C1.2, MCU_C2.1, MCU_C3.1, MCU_C4.1, MCU_C5.1, MCU_C6.1, MCU_C7.1, MCU_C8.1, MCU_C9.1, REG1.1 (GND), REG_C1.2, REG_C2.2, USB1.A1 (GND), USB1.A12 (GND), USB1.B1 (GND), USB1.B12 (GND), USB1.S1 (SHIELD), USB_R1.2, USB_R2.2; also elsewhere on the board
unnamed: USB1.A5 (CC1), USB_R1.1
unnamed: USB1.B5 (CC2), USB_R2.1
RGB: MCU1.38 (PA15); also elsewhere on the board
Row0: MCU1.29 (PA8); also elsewhere on the board
Row1: MCU1.28 (PB15); also elsewhere on the board
Row2: MCU1.27 (PB14); also elsewhere on the board
Row3: MCU1.26 (PB13); also elsewhere on the board
Row4: MCU1.25 (PB12); also elsewhere on the board
VBUS: ESD1.5 (VBUS), F1.1, USB1.A4 (VBUS), USB1.A9 (VBUS), USB1.B4 (VBUS), USB1.B9 (VBUS)

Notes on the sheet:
Controller
USB-C
Mounting Holes
Voltage Step Down
Power Flags
ESD Protection
Connector
Decoupling Capacitors
STM32F072CBT6
Other
Bootloader Button
Hold when plugging in to enter bootloader mode.

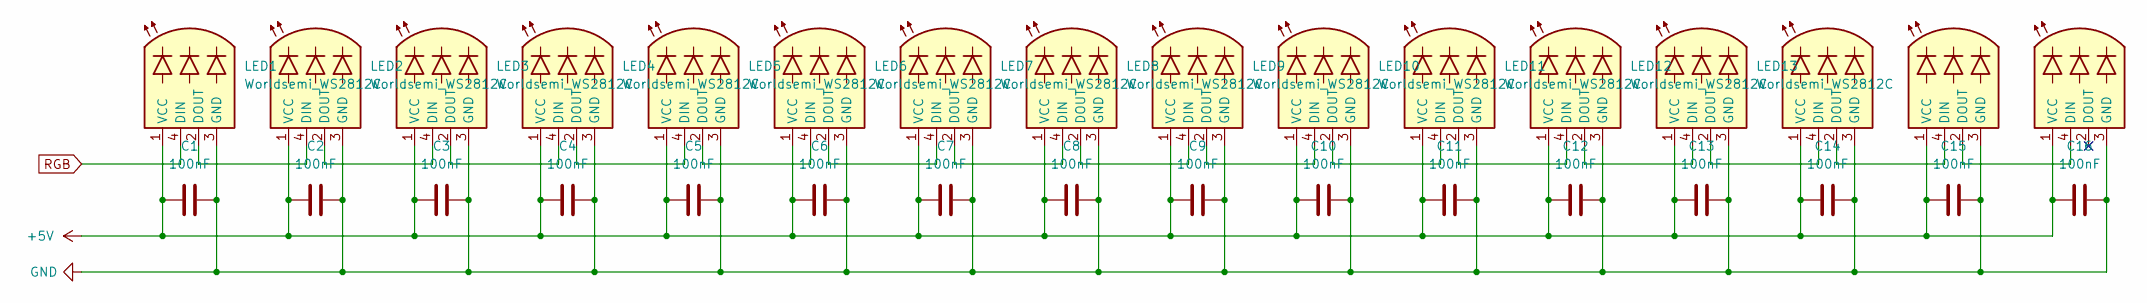
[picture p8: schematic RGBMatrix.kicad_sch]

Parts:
C1, C2, C3, C4, C5, C6, C7, C8, C9, C10, C11, C12, C13, C14, C15, C16: 100nF; C_0603_1608Metric_Pad1.08x0.95mm; LCSC C1591
LED1, LED2, LED3, LED4, LED5, LED6, LED7, LED8, LED9, LED10, LED11, LED12, LED13, LED14, LED15, LED16: Worldsemi_WS2812C; LED_WS2812B_PLCC4_5.0x5.0mm_P3.2mm; LCSC C114587

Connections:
+5V: C1.1, C2.1, C3.1, C4.1, C5.1, C6.1, C7.1, C8.1, C9.1, C10.1, C11.1, C12.1, C13.1, C14.1, C15.1, C16.1, LED1.1 (VCC), LED2.1 (VCC), LED3.1 (VCC), LED4.1 (VCC), LED5.1 (VCC), LED6.1 (VCC), LED7.1 (VCC), LED8.1 (VCC), LED9.1 (VCC), LED10.1 (VCC), LED11.1 (VCC), LED12.1 (VCC), LED13.1 (VCC), LED14.1 (VCC), LED15.1 (VCC), LED16.1 (VCC); also elsewhere on the board
GND: C1.2, C2.2, C3.2, C4.2, C5.2, C6.2, C7.2, C8.2, C9.2, C10.2, C11.2, C12.2, C13.2, C14.2, C15.2, C16.2, LED1.3 (GND), LED2.3 (GND), LED3.3 (GND), LED4.3 (GND), LED5.3 (GND), LED6.3 (GND), LED7.3 (GND), LED8.3 (GND), LED9.3 (GND), LED10.3 (GND), LED11.3 (GND), LED12.3 (GND), LED13.3 (GND), LED14.3 (GND), LED15.3 (GND), LED16.3 (GND); also elsewhere on the board
unnamed: LED1.2 (DOUT), LED2.4 (DIN)
unnamed: LED2.2 (DOUT), LED3.4 (DIN)
unnamed: LED3.2 (DOUT), LED4.4 (DIN)
unnamed: LED4.2 (DOUT), LED5.4 (DIN)
unnamed: LED5.2 (DOUT), LED6.4 (DIN)
unnamed: LED6.2 (DOUT), LED7.4 (DIN)
unnamed: LED7.2 (DOUT), LED8.4 (DIN)
unnamed: LED8.2 (DOUT), LED9.4 (DIN)
unnamed: LED9.2 (DOUT), LED10.4 (DIN)
unnamed: LED10.2 (DOUT), LED11.4 (DIN)
unnamed: LED11.2 (DOUT), LED12.4 (DIN)
unnamed: LED12.2 (DOUT), LED13.4 (DIN)
unnamed: LED13.2 (DOUT), LED14.4 (DIN)
unnamed: LED14.2 (DOUT), LED15.4 (DIN)
unnamed: LED15.2 (DOUT), LED16.4 (DIN)
RGB: LED1.4 (DIN); also elsewhere on the board

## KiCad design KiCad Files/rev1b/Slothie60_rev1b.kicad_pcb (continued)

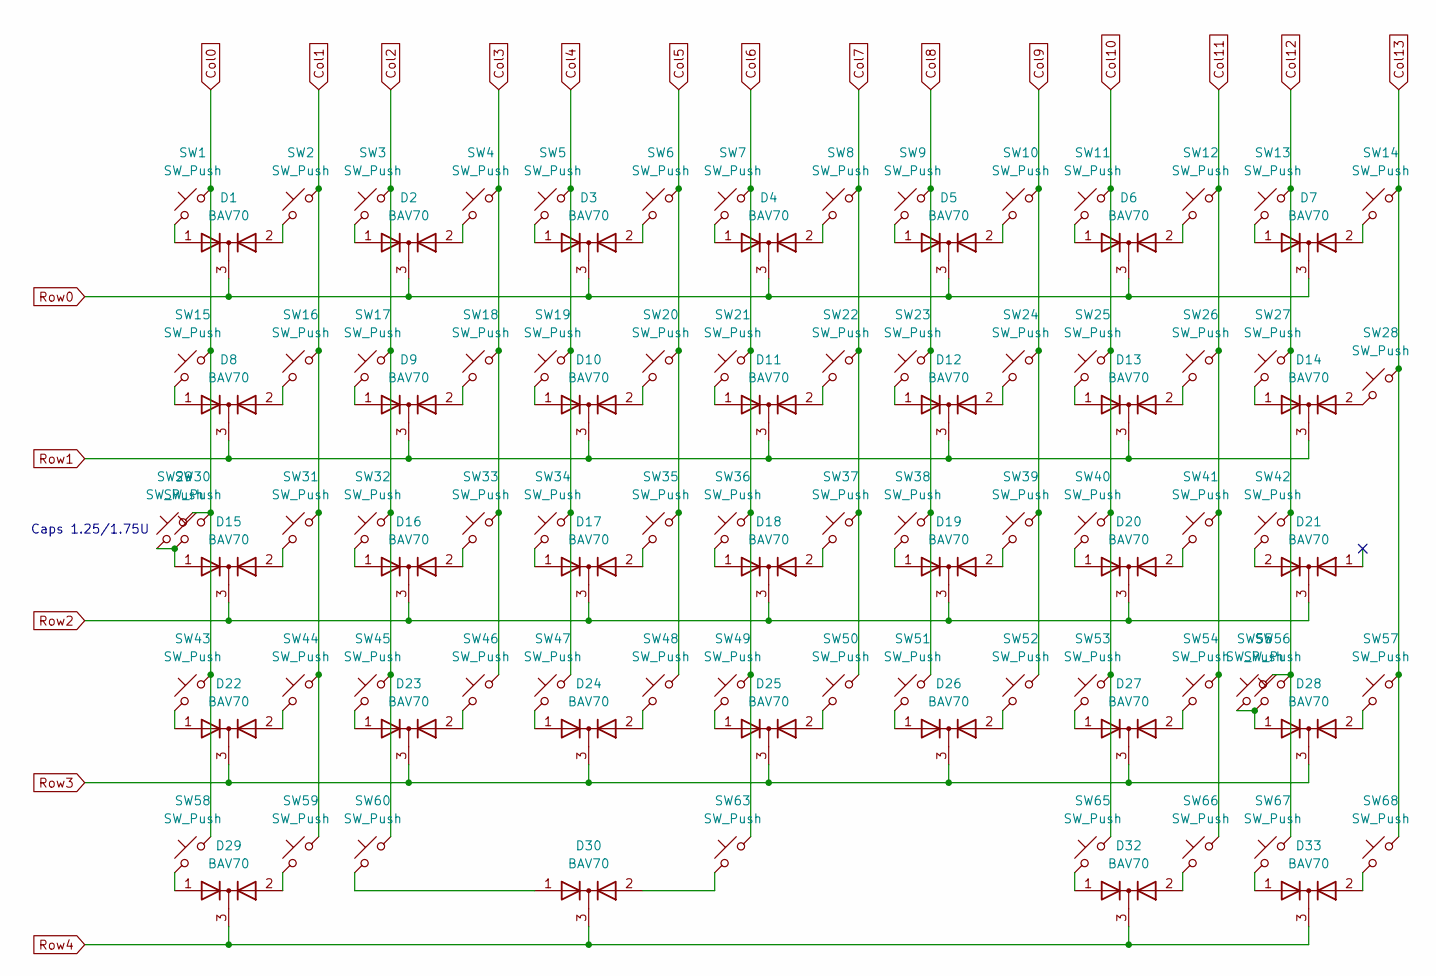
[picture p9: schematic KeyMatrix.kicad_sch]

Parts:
D1, D2, D3, D4, D5, D6, D7, D8, D9, D10, D11, D12, D13, D14, D15, D16, D17, D18, D19, D20, D21, D22, D23, D24, D25, D26, D27, D28, D29, D30, D32, D33: BAV70; SOT-23; LCSC C2501
SW1, SW2, SW3, SW4, SW5, SW6, SW7, SW8, SW9, SW10, SW11, SW12, SW13, SW16, SW17, SW18, SW19, SW20, SW21, SW22, SW23, SW24, SW25, SW26, SW27, SW31, SW32, SW33, SW34, SW35, SW36, SW37, SW38, SW39, SW40, SW41, SW42, SW44, SW45, SW46, SW47, SW48, SW49, SW50, SW51, SW52, SW53, SW54, SW57: SW_Push; SW_Hotswap_Kailh_MX_Plated_1.00u; LCSC C5156480
SW14: SW_Push; SW_Hotswap_Kailh_MX_Plated_2.00u; LCSC C5156480
SW15: SW_Push; SW_Hotswap_Kailh_MX_Plated_1.50u; LCSC C5156480
SW28: SW_Push; SW_Hotswap_Kailh_MX_Plated_ISOEnter; LCSC C5156480
SW29, SW43, SW58, SW59, SW60, SW65, SW66, SW67, SW68: SW_Push; SW_Hotswap_Kailh_MX_Plated_1.25u; LCSC C5156480
SW30, SW55: SW_Push; SW_Hotswap_Kailh_MX_Plated_1.75u; LCSC C5156480
SW56: SW_Push; SW_Hotswap_Kailh_MX_Plated_2.75u; LCSC C5156480
SW63: SW_Push; SW_Hotswap_Kailh_MX_Plated_6.25u; LCSC C5156480

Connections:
Col0: SW1.1, SW15.1, SW29.1, SW30.1, SW43.1, SW58.1; also elsewhere on the board
Col1: SW2.1, SW16.1, SW31.1, SW44.1, SW59.1; also elsewhere on the board
Col2: SW3.1, SW17.1, SW32.1, SW45.1, SW60.1; also elsewhere on the board
Col3: SW4.1, SW18.1, SW33.1, SW46.1; also elsewhere on the board
Col4: SW5.1, SW19.1, SW34.1, SW47.1; also elsewhere on the board
Col5: SW6.1, SW20.1, SW35.1, SW48.1; also elsewhere on the board
Col6: SW7.1, SW21.1, SW36.1, SW49.1, SW63.1; also elsewhere on the board
Col7: SW8.1, SW22.1, SW37.1, SW50.1; also elsewhere on the board
Col8: SW9.1, SW23.1, SW38.1, SW51.1; also elsewhere on the board
Col9: SW10.1, SW24.1, SW39.1, SW52.1; also elsewhere on the board
Col10: SW11.1, SW25.1, SW40.1, SW53.1, SW65.1; also elsewhere on the board
Col11: SW12.1, SW26.1, SW41.1, SW54.1, SW66.1; also elsewhere on the board
Col12: SW13.1, SW27.1, SW42.1, SW55.1, SW56.1, SW67.1; also elsewhere on the board
Col13: SW14.1, SW28.1, SW57.1, SW68.1; also elsewhere on the board
unnamed: D1.1 (A), SW1.2
unnamed: D1.2 (A), SW2.2
unnamed: D2.1 (A), SW3.2
unnamed: D2.2 (A), SW4.2
unnamed: D3.1 (A), SW5.2
unnamed: D3.2 (A), SW6.2
unnamed: D4.1 (A), SW7.2
unnamed: D4.2 (A), SW8.2
unnamed: D5.1 (A), SW9.2
unnamed: D5.2 (A), SW10.2
unnamed: D6.1 (A), SW11.2
unnamed: D6.2 (A), SW12.2
unnamed: D7.1 (A), SW13.2
unnamed: D7.2 (A), SW14.2
unnamed: D8.1 (A), SW15.2
unnamed: D8.2 (A), SW16.2
unnamed: D9.1 (A), SW17.2
unnamed: D9.2 (A), SW18.2
unnamed: D10.1 (A), SW19.2
unnamed: D10.2 (A), SW20.2
unnamed: D11.1 (A), SW21.2
unnamed: D11.2 (A), SW22.2
unnamed: D12.1 (A), SW23.2
unnamed: D12.2 (A), SW24.2
unnamed: D13.1 (A), SW25.2
unnamed: D13.2 (A), SW26.2
unnamed: D14.1 (A), SW27.2
unnamed: D14.2 (A), SW28.2
unnamed: D15.1 (A), SW29.2, SW30.2
unnamed: D15.2 (A), SW31.2
unnamed: D16.1 (A), SW32.2
unnamed: D16.2 (A), SW33.2
unnamed: D17.1 (A), SW34.2
unnamed: D17.2 (A), SW35.2
unnamed: D18.1 (A), SW36.2
unnamed: D18.2 (A), SW37.2
unnamed: D19.1 (A), SW38.2
unnamed: D19.2 (A), SW39.2
unnamed: D20.1 (A), SW40.2
unnamed: D20.2 (A), SW41.2
unnamed: D21.2 (A), SW42.2
unnamed: D22.1 (A), SW43.2
unnamed: D22.2 (A), SW44.2
unnamed: D23.1 (A), SW45.2
unnamed: D23.2 (A), SW46.2
unnamed: D24.1 (A), SW47.2
unnamed: D24.2 (A), SW48.2
unnamed: D25.1 (A), SW49.2
unnamed: D25.2 (A), SW50.2
unnamed: D26.1 (A), SW51.2
unnamed: D26.2 (A), SW52.2
unnamed: D27.1 (A), SW53.2
unnamed: D27.2 (A), SW54.2
unnamed: D28.1 (A), SW55.2, SW56.2
unnamed: D28.2 (A), SW57.2
unnamed: D29.1 (A), SW58.2
unnamed: D29.2 (A), SW59.2
unnamed: D30.1 (A), SW60.2
unnamed: D30.2 (A), SW63.2
unnamed: D32.1 (A), SW65.2
unnamed: D32.2 (A), SW66.2
unnamed: D33.1 (A), SW67.2
unnamed: D33.2 (A), SW68.2
Row0: D1.3 (K), D2.3 (K), D3.3 (K), D4.3 (K), D5.3 (K), D6.3 (K), D7.3 (K); also elsewhere on the board
Row1: D8.3 (K), D9.3 (K), D10.3 (K), D11.3 (K), D12.3 (K), D13.3 (K), D14.3 (K); also elsewhere on the board
Row2: D15.3 (K), D16.3 (K), D17.3 (K), D18.3 (K), D19.3 (K), D20.3 (K), D21.3 (K); also elsewhere on the board
Row3: D22.3 (K), D23.3 (K), D24.3 (K), D25.3 (K), D26.3 (K), D27.3 (K), D28.3 (K); also elsewhere on the board
Row4: D29.3 (K), D30.3 (K), D32.3 (K), D33.3 (K); also elsewhere on the board

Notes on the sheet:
Caps 1.25/1.75U

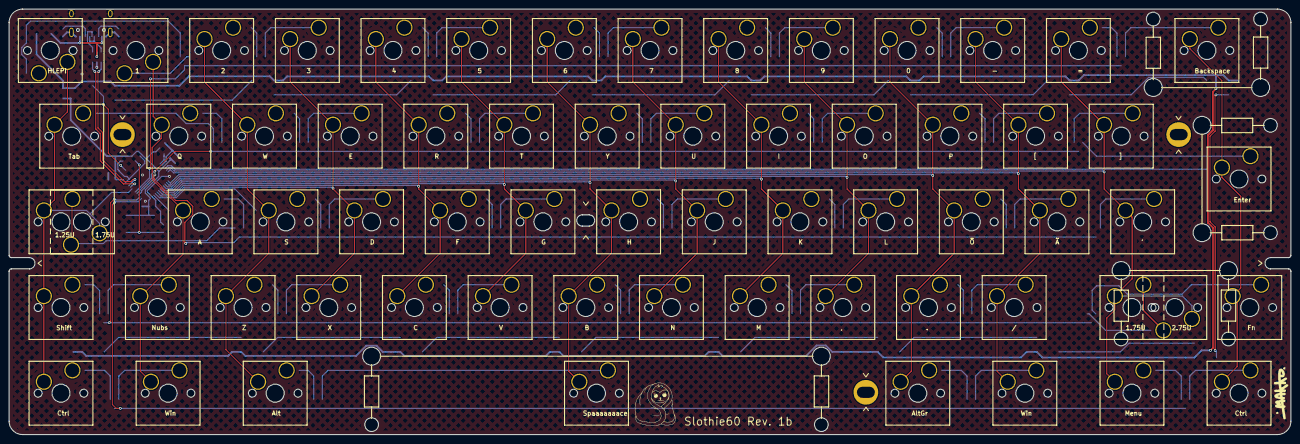
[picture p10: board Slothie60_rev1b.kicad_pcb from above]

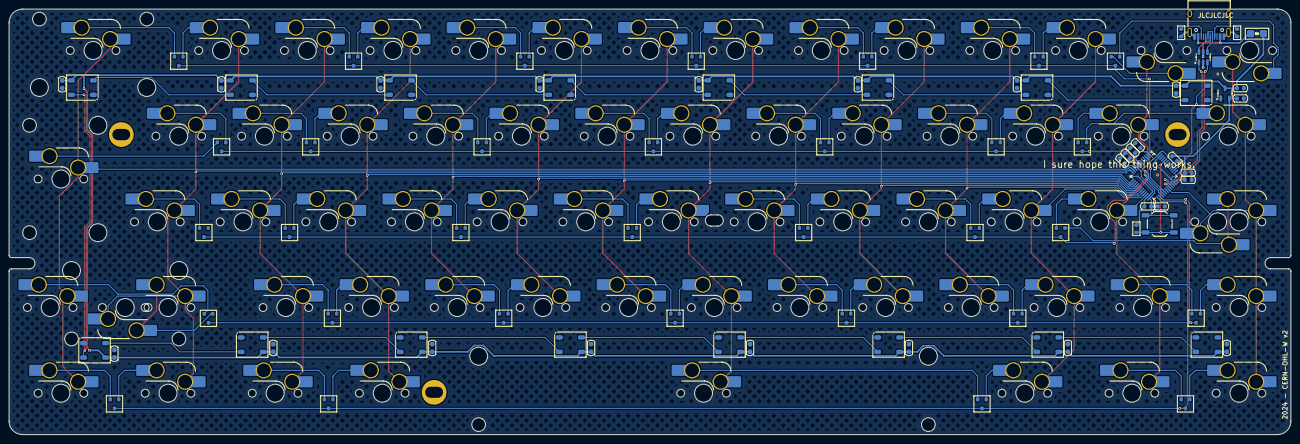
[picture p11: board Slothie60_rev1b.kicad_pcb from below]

Board: 2 copper layers, 285.0 x 94.6 mm, 149 parts (84 on the bottom side), 110 nets.

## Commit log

2025-02-19 First commit
    - Added KiCad files
    - Added Production files for ordering
    - Added first version of firmware
    - Edited readme
    [KeyMatrix.kicad_sch, RGBMatrix.kicad_sch, Slothie60_rev1a.kicad_sch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]
2025-03-13 Update
    KiCad files had one small error, fixed it now
    [KeyMatrix.kicad_sch, RGBMatrix.kicad_sch, Slothie60_rev1a.kicad_pcb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]
2025-04-10 Updated to 1b
    - Removed split space
    - Updated led count and the pin
    - Updated firmware
2025-04-10 Update to revision 1b
    - Updated to 16 5050-leds
    - Changed to round routing
    - Updated production and KiCad-folders to 9.0.1
    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
    [KeyMatrix.kicad_sch, RGBMatrix.kicad_sch, Slothie60_rev1a.kicad_pcb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]
2026-02-18 New revision
    - Moved 1b to it's own folder
    - Added folder 1c with base files to KiCad files (WIP, DO NOT USE)
    [KeyMatrix.kicad_sch, RGBMatrix.kicad_sch, Slothie60_rev1b-rounded.kicad_pcb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]
2026-02-18 Rev1c preliminarty update
    Changes to Schematic:
    - Added switches to support different layouts
    - Added One BAV70 to support said switches
    Changes to PCB:
    - Imported changes from schematic, placed some of the switches but needs more work
    [KeyMatrix.kicad_sch, rev1c.kicad_pcb, rev1c.kicad_sch]
2026-02-18 update on pcb
    [KeyMatrix.kicad_sch, rev1c.kicad_pcb]
2026-02-21 FR4 Plate
    Plate done
    [designators.csv, rev1c.kicad_pcb, rev1c.kicad_plate.kicad_pcb]
2026-03-10 Plate stuff
    - Added a plate design for rev 1b
    - Some updates to 1c
    [Slothie60_rev1b-rounded.step, bom.csv, designators.csv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]
2026-09-03 rev2a
    - basic layout
    - leds
    - rp2040 with all necessary things
    [KeyMatrix.kicad_sch, RGBMatrix.kicad_sch, Rev.2a.kicad_pcb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]
2026-10-30 Big Update
    - KiCad updated to version 10
    - Schematics are done
    - PCB 98% done, prototype ordered
2026-11-01 Firmware update
    - Added keymaps for base QMK
    - Added keymaps for VIAL for fast switching between different layouts

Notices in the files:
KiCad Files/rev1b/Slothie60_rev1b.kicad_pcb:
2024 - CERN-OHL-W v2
